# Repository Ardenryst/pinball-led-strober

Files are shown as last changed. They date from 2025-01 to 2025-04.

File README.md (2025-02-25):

# Project description

This is a simple platform to add mods with light effects to an existing pinball machine.
The board connected to an existing lamp and once this lights up, the boards triggers its own animation. Simple as that.

Find details about hardware and firmware in their respective folders.

This project is free hardware/software, use it for your own projects if your like and let me know when you made something great!

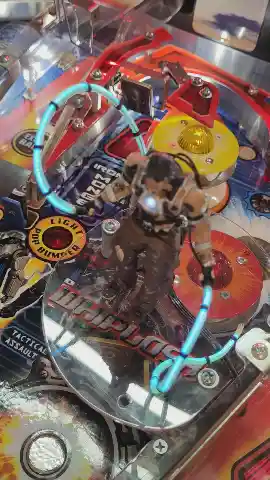
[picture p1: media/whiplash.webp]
Whiplash


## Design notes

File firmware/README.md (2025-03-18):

# Firmware

Firmware is written in C and has no external dependencies.

**Info** This software is very minimal and likely to change in the future.

## Building

While this is NOT an Arduino project, the easiest way to get all the necessary development tools is in fact to use what comes bundled with Arduino. If you already have Arduino installed, follow these steps, otherwise I'd recommend using `arduino-cli` instead.

### Setup using Arduino

So you're already using Arduino? Then you can use that. But first you may have to install the package `ATTinyCore` via the board manager. This may require to add the line `http://drazzy.com/package_drazzy.com_index.json` to "Additional Boards Manager URLs". **Nope, not needed!**

### Setup using arduino-cli

 > **This is nonsense! Headers and advdude config is part of arduino distribution already! But I think this still need to be installed as cli comes without any cores, correct?**

This option saves a lot of the bloat that comes with a standard Arduino installation.

1. Check the documentation for the preferred way to install `arduino-cli` on your platform. Then enter the terminal.

2. Install core: `arduino-cli core install arduino:avr`

3. `arduino-cli config dump` to check the directories you have to look for the toolchain to complete the next step. These are located under `directories>data`.

### Configure build system

The firmware is build via `make`. This tool is pre-installed under many systems, for Windows the easiest way would be to use `WSL`.

To tell it where your compiler and other tools are, an `Makefile.in` file is required. You can use copy the existing `Makefile.in.template` and adjust it to your needs. There is example configurations for both Mac and Linux included. Find the base path in the output from the previous step.

Make sure to correctly set the paths that point to the tool binaries, depending on your specific machine setup and program versions these may vary.

### Compile

Run `make` from the firmware root directory to build the software.

### Set fuses

To prime chip the fuse bits have to be flashed first. This configures hardware functions like clock speed etc. of the MCU. Use `make burn_fuses` for this. This has only to be done once since uploading firmware file does not touch the fuse settings.

### Upload firmware

Run `make program` to flash the firmware. This will upload the build to the target. The execution should start immediately once upload is completed.

`make && make program` will rebuild the project and, if successful, then upload it. This is convenient during development.

## Changing animation

There is no way to configure anything at this point, you'll have to hack away at the code. This should be easy enough for everyone who is familiar with C to some degree, since the code is really not that complex.

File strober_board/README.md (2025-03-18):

# Hardware description

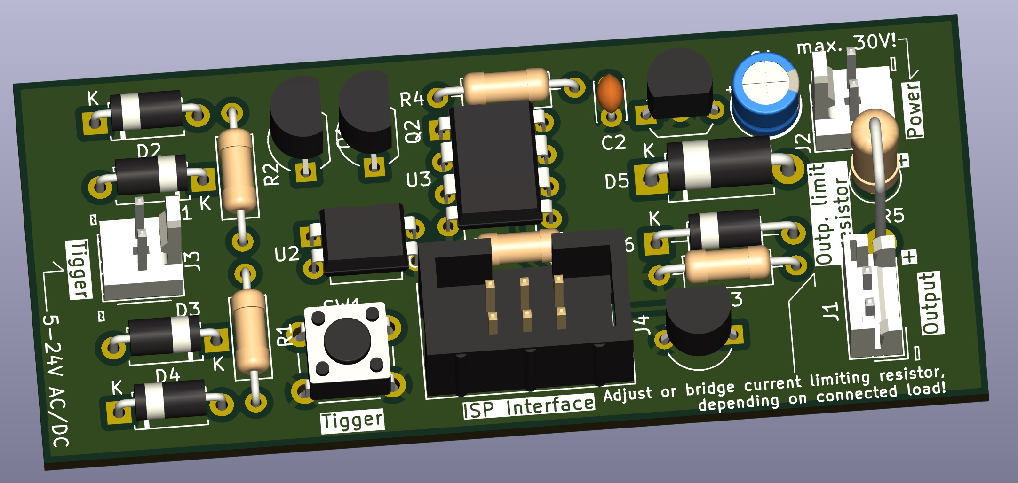
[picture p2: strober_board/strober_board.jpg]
Title


The hardware is build around the `Attiny85` microcontroller (MCU), a cheap yet capable chip. To program the firmware onto the controller, an ISP (in-system programmer) is needed. You can also use something like an Arduino with the correct sketch loaded onto it.

The electronics need an external supply of 8-30V DC, reverse polarity protected local regulation is on board. The animation is triggered by an external current, the board is intended to be connected to an existing lamp and triggers as soon as this turns on. The trigger input can accept a wide voltage range of 5 to at least 24V, with no concern to polarity. For testing there is also a trigger button on the board itself that simulates an external event. Trigger input is galvanically isolated from rest of curcuit via an opto-coupler, to avoid issues with matrix switching or split power rails.

The output is connected to the board supply voltage through a current limiting resistor (R5), that has to be selected for the connected load or bridged with a jumper, if not needed. The MCU controls the output with a 12bit PWM signal, thus allowing 4096 levels of brightness with smooth fading. Output is protected against back EMF from inductive loads (e.g. EL-Wire power supply) and can supply up to 500mA of continious current.

The PCB design can either be send to a manufacturer (use the includes `Gerber-files`) or build on a commonly availible 10x23 hole proto board. Both options share the same physical board size of 30x70mm. Take a look into the interactive bill of materials `bom-folder` for what parts need to be sourced - it also greatly helps in assembly!

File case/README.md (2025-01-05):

# Part description

This is a simple casing, that can be used to mount the board under the playfield using 2-4 #8 wood screws, as they are commonly found in virtually every pinball machine ever produced.
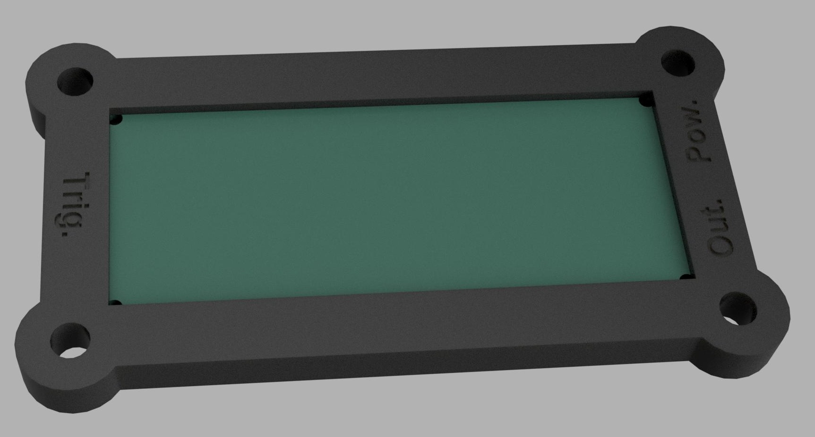
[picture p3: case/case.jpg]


The case consist of two pieces and can be created without any special settings or support structures on practically any 3D printer.

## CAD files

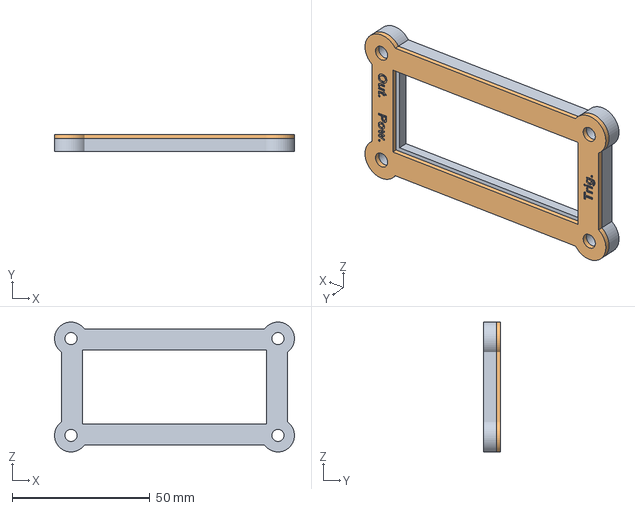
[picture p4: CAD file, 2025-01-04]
case/case.3mf
87.2 x 6.10 x 47.2 mm

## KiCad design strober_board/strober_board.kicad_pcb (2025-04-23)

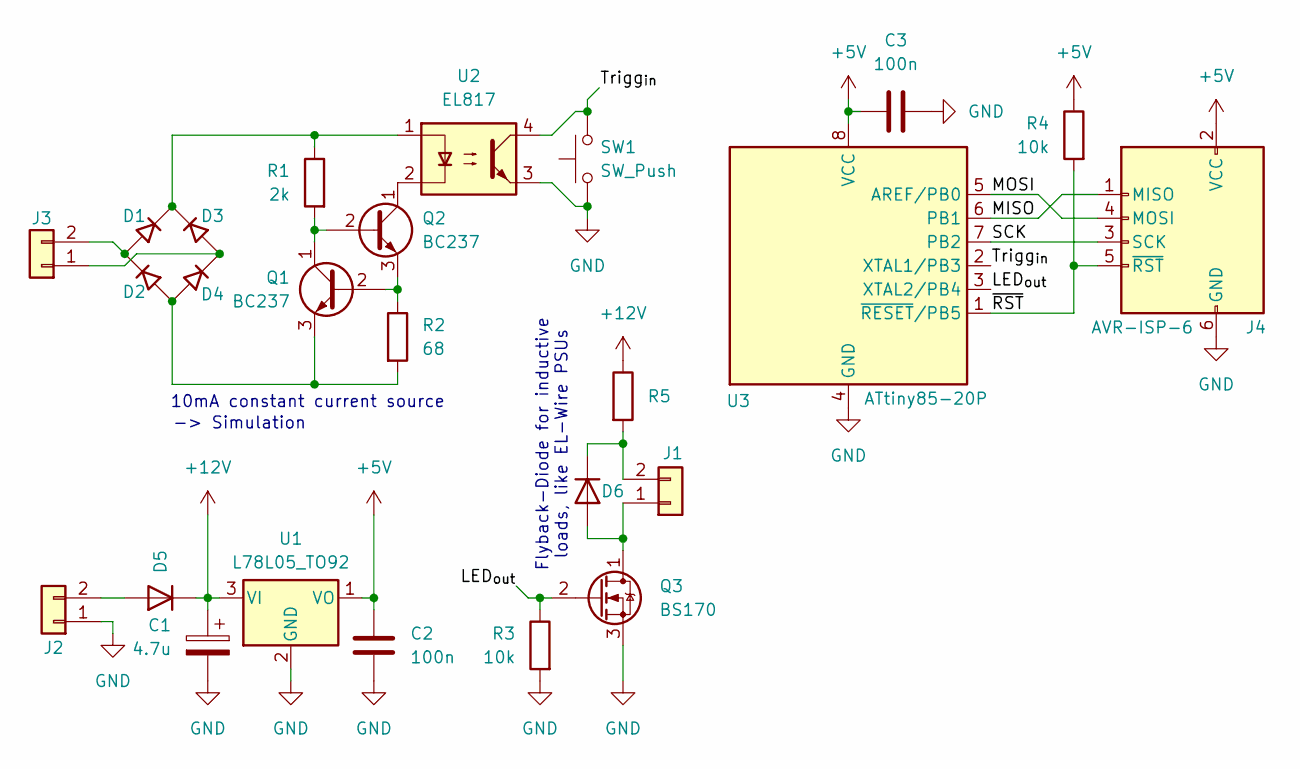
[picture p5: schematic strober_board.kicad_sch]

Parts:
C1: 4.7u; CP_Radial_D5.0mm_P2.50mm
C2: 100n; C_Disc_D3.0mm_W2.0mm_P2.50mm
C3: 100n; R_Axial_DIN0207_L6.3mm_D2.5mm_P10.16mm_Horizontal
D1, D2, D3, D4: D_45deg; D_A-405_P7.62mm_Horizontal
D5: D; D_DO-15_P10.16mm_Horizontal
D6: D; D_A-405_P10.16mm_Horizontal
J1: Conn_01x02; JST_EH_B2B-EH-A_1x02_P2.50mm_Vertical
J2, J3: Conn_01x02; Molex_KK-254_AE-6410-02A_1x02_P2.54mm_Vertical
J4: AVR-ISP-6; IDC-Header_2x03_P2.54mm_Vertical
Q1, Q2: BC237; TO-92_Inline_Wide
Q3: BS170; TO-92_Inline_Wide
R1: 2k; R_Axial_DIN0207_L6.3mm_D2.5mm_P10.16mm_Horizontal
R2: 68; R_Axial_DIN0207_L6.3mm_D2.5mm_P10.16mm_Horizontal
R3, R4: 10k; R_Axial_DIN0207_L6.3mm_D2.5mm_P10.16mm_Horizontal
R5: R_Axial_DIN0411_L9.9mm_D3.6mm_P5.08mm_Vertical
SW1: SW_Push; SW_PUSH_6mm
U1: L78L05_TO92; TO-92_Inline_Wide
U2: EL817; DIP-4_W7.62mm
U3: ATtiny85-20P; DIP-8_W7.62mm

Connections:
+5V: C2.2, C3.1, J4.2 (VCC), R4.1, U1.1 (VO), U3.8 (VCC)
+12V: C1.1, D5.1 (K), R5.1, U1.3 (VI)
/LED_{out}: Q3.2 (G), R3.1, U3.3 (XTAL2/PB4)
/MISO: J4.1 (MISO), U3.6 (PB1)
/MOSI: J4.4 (MOSI), U3.5 (AREF/PB0)
/SCK: J4.3 (SCK), U3.7 (PB2)
/Trigg_{in}: SW1.2, U2.4, U3.2 (XTAL1/PB3)
/~RST: J4.5 (~RST), R4.2, U3.1 (~RESET/PB5)
GND: C1.2, C2.1, C3.2, J2.1, J4.6 (GND), Q3.3 (S), R3.2, SW1.1, U1.2 (GND), U2.3, U3.4 (GND)
unnamed: D1.2 (A), D2.1 (K), J3.2
unnamed: D1.1 (K), D3.1 (K), R1.1, U2.1
unnamed: D2.2 (A), D4.2 (A), Q1.3 (E), R2.2
unnamed: D3.2 (A), D4.1 (K), J3.1
unnamed: D5.2 (A), J2.2
unnamed: D6.2 (A), J1.1, Q3.1 (D)
unnamed: D6.1 (K), J1.2, R5.2
unnamed: Q1.2 (B), Q2.3 (E), R2.1
unnamed: Q1.1 (C), Q2.2 (B), R1.2
unnamed: Q2.1 (C), U2.2

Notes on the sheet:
Flyback-Diode for inductive loads, like EL-Wire PSUs
-> Simulation
10mA constant current source

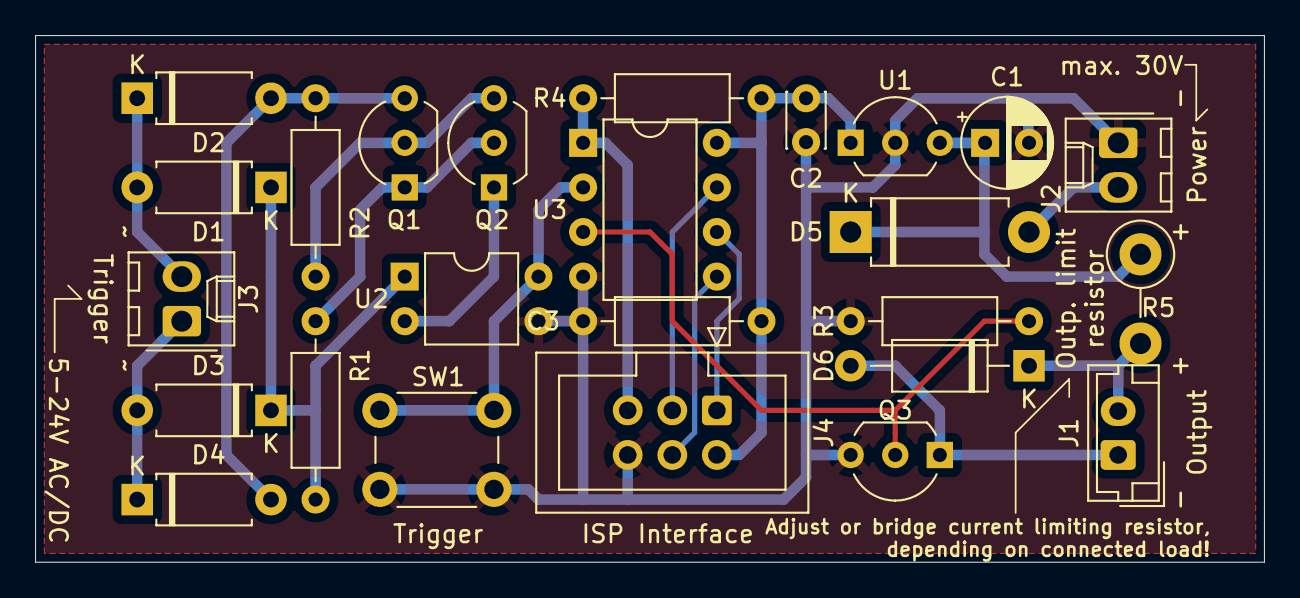
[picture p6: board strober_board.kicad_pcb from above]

Board: 2 copper layers, 70.0 x 30.0 mm, 25 parts (0 on the bottom side), 19 nets.

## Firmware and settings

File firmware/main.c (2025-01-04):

#include <stdlib.h>
#include <stdio.h>
#include <stdbool.h>
#include <stdint.h>
#include <string.h>

#include <util/delay.h>
#include <avr/io.h>
#include <avr/eeprom.h>
#include <avr/interrupt.h>
#include <util/atomic.h>
#include <avr/pgmspace.h>

#include <util.h>

#define LED   B, 4
#define TX    B, 2
#define BTN   B, 3
static volatile uint8_t* pwm_channels[] = { &OCR1B, /*&OCR1A */};

// Source: https://www.mikrocontroller.net/topic/311610#3362049
int uart_putchar(char c, FILE *stream) {
  #define DEBUG_PIN B, 2

  #define DEBUG_HIGH  PORT(DEBUG_PIN) = 1
  #define DEBUG_LOW  PORT(DEBUG_PIN) = 0

  //Wartezeit in us 
  #define MINDELAY    104     // fuer 9600 bps
  // #define MINDELAY    26     // fuer 38400 bps
  // #define MINDELAY   417    // fuer 2400 bps ACHTUNG nicht mit _delay_us machtbar!!
                // zumindest nicht als einzelner aufruf!
  OUTPUT(DEBUG_PIN);
  PORT(DEBUG_PIN) = 1;

  PORT(DEBUG_PIN) = 0;
  _delay_us(MINDELAY);               // Start Bit

  for(uint8_t i=0; i<8; i++) {
    if(c & (0x01<<i)) {
      PORT(DEBUG_PIN) = 1;
    } else {
      PORT(DEBUG_PIN) = 0;
    }
    _delay_us(MINDELAY);
  }
  PORT(DEBUG_PIN) = 1;        // Stop Bit
  _delay_us(MINDELAY);

  return 0;
}

// Higher bit PWM sources:
//  - https://www.arduinoslovakia.eu/blog/2017/12/10-bitove-pwm-na-attiny85?lang=en
//  - http://www.technoblogy.com/show?1NGL

volatile int dac[SIZE(pwm_channels)];

void initPWM() {
 OCR1C = 255;
  // Timer/Counter1 doing PWM on OC1A (PB1)
  TCCR1 = 1 << PWM1A    // Pulse Width Modulator A Enable
          | 1 << COM1A0 // OC1x cleared on compare match. Set when TCNT1 = $00
          | 0 << CS10 | 0 << CS11 | 1 << CS12;  // TODO prüfen, ob man das so macht. Durch rumprobieren bei 250Hz PWM-Frew gelandet.
  TIMSK |= 1 << TOIE1; // Timer/Counter1 Overflow Interrupt Enable
  
  GTCCR = 1<<PWM1B | 1<<COM1B1; // What kind of shitty register naming is that?!
}

// 12bit DAC
// Overflow interrupt
ISR(TIMER1_OVF_vect) {
  static volatile int cycle = 0;
  static int rem[SIZE(pwm_channels)];
  for(int chan=0; chan<SIZE(pwm_channels); chan++) {
    int remain;
    if(cycle==0) {
      remain = dac[chan];
    } else {
      remain = rem[chan];
    }
    if(remain>=256) {
      *pwm_channels[chan] = 255; remain = remain - 256;
    } else {
      *pwm_channels[chan] = remain; remain = 0;
    }
    rem[chan] = remain;
  }
  cycle = (cycle+1) & 0x0F;
}

const uint16_t PROGMEM gamma_8b[] = {
  0,    0,    0,    0,    1,    1,    2,    3,    4,    6,    8,   10,   13,   16,   19,   24,
  28,   33,   39,   46,   53,   60,   69,   78,   88,   98,  110,  122,  135,  149,  164,  179,
  196,  214,  232,  252,  273,  295,  317,  341,  366,  393,  420,  449,  478,  510,  542,  575,
  610,  647,  684,  723,  764,  806,  849,  894,  940,  988, 1037, 1088, 1140, 1194, 1250, 1307,
  1366, 1427, 1489, 1553, 1619, 1686, 1756, 1827, 1900, 1975, 2051, 2130, 2210, 2293, 2377, 2463,
  2552, 2642, 2734, 2829, 2925, 3024, 3124, 3227, 3332, 3439, 3548, 3660, 3774, 3890, 4008, 4128,
  4251, 4376, 4504, 4634, 4766, 4901, 5038, 5177, 5319, 5464, 5611, 5760, 5912, 6067, 6224, 6384,
  6546, 6711, 6879, 7049, 7222, 7397, 7576, 7757, 7941, 8128, 8317, 8509, 8704, 8902, 9103, 9307,
  9514, 9723, 9936, 10151, 10370, 10591, 10816, 11043, 11274, 11507, 11744, 11984, 12227, 12473, 12722, 12975,
  13230, 13489, 13751, 14017, 14285, 14557, 14833, 15111, 15393, 15678, 15967, 16259, 16554, 16853, 17155, 17461,
  17770, 18083, 18399, 18719, 19042, 19369, 19700, 20034, 20372, 20713, 21058, 21407, 21759, 22115, 22475, 22838,
  23206, 23577, 23952, 24330, 24713, 25099, 25489, 25884, 26282, 26683, 27089, 27499, 27913, 28330, 28752, 29178,
  29608, 30041, 30479, 30921, 31367, 31818, 32272, 32730, 33193, 33660, 34131, 34606, 35085, 35569, 36057, 36549,
  37046, 37547, 38052, 38561, 39075, 39593, 40116, 40643, 41175, 41711, 42251, 42796, 43346, 43899, 44458, 45021,
  45588, 46161, 46737, 47319, 47905, 48495, 49091, 49691, 50295, 50905, 51519, 52138, 52761, 53390, 54023, 54661,
  55303, 55951, 56604, 57261, 57923, 58590, 59262, 59939, 60621, 61308, 62000, 62697, 63399, 64106, 64818, 65535
};

// more or less copy pasted and updated, with no real idea what I was doing. Seems to work OK though...
uint16_t correctGamma12(uint16_t value) {
  uint16_t y = pgm_read_word(&gamma_8b[value / 16]);
  uint16_t z1 = (value / 16 == 0) ? 0 : pgm_read_word(&gamma_8b[value / 16 - 1]);
  uint16_t z = (y - z1) / 16 * (value % 16 + 1) + z1;

  return z >> 6;
}

const uint8_t exptable5[32] PROGMEM =
  {130, 133, 136, 139, 142, 145, 148, 151, 155, 158, 161, 165, 169, 172, 176, 180,
  184, 188, 192, 196, 201, 205, 210, 214, 219, 224, 229, 234, 239, 244, 249, 255};

/*inline*/ uint16_t expvalue9(const uint16_t linear)
{/* Returns the exponential value (approx. 1.0219^x).                          *
  * argument: 9 bit unsigned (0..511)  return: 16 bit unsigned (1..65280)    */
  // look up exponential
  uint16_t exp = pgm_read_byte(&exptable5[ linear % 32 ]) << 8;
  // scale magnitude
  return exp >> (15 - linear / 32);
}

// #define BASE_BRIGHTNESS 20
// // #define MAX_BRIGHTNESS 100
// #define BRIGHTNESS_VARIANCE (100-BASE_BRIGHTNESS)

// Basishelligkeit, bezogen auf max. Umgebungshelligkeit
#define BASE_BRIGHTNESS 3000
// +/- var/2 auf Basishelligkeit
#define BRIGHTNESS_VARIANCE 2200
// Faktor für Überhöhung der Bezugshelligkeit aus der Umgebung
#define ELEVATION 1.3

#define MIN_FADE_TIME 50
#define FADE_TIME_VARIANCE 100

#define MIN_HOLD_TIME 100
#define HOLD_TIME_VARIANCE 200

struct Led {
  volatile int *dac;
//   const uint16_t MIN_BRIGHTNESS;
  // const uint16_t MAX_BRIGHTNESS;
  struct Timer fade_timer;
  uint16_t start;
  uint16_t goal;
} leds[] = {
  {.dac = &dac[0]},
};
inline void fade(struct Led *led, uint16_t from, uint16_t to, uint16_t duration) {
  resetTimer(&led->fade_timer);
  led->fade_timer.cycle = duration;
  led->start = from;
  led->goal = to;
}

// struct {
//   bool is_pushed;
//   //uint8_t samples;
//   struct Timer sample_timer;
// } button = {false, 0, {1}};

int main() {
  initMillis();
  initPWM();
  
  FILE soft_uart = FDEV_SETUP_STREAM(uart_putchar, NULL, _FDEV_SETUP_WRITE);
  stdout = &soft_uart;
  
  OUTPUT(LED);
  OUTPUT(TX);
  INPUT_PULLUP(BTN);
  
  enum States {INIT, STANDBY, FLASH};
  struct StateMachine fsm;
  initFSM(&fsm, INIT);
  
  // #define MAX_BRIGHTNESS 4096
  // #define MIN_BRIGHTNESS 0
  // #define DURATION 10000
  
  // struct Timer timer = {.cycle=DURATION};
  // bool dir = true;
  while(true) {
    // if(checkAndResetTimer(&timer)) {
    //   dir = !dir;
    //   fade(&leds[0], dir ? MAX_BRIGHTNESS : MIN_BRIGHTNESS, dir ? MIN_BRIGHTNESS: MAX_BRIGHTNESS, DURATION);
    // }
    
//     if(checkAndResetTimer(&button.sample_timer)) {
//       if(PIN(BTN)==0) {
//         if(button.samples < 10) {
//           button.samples++;
//         } else {
//           if(!button.is_pushed) {
//             transit(&fsm, fsm.current_state == ON ? OFF : ON);
//             button.is_pushed = true;
//           }
//         }
//       } else {
//         button.samples = 0;
//         button.is_pushed = false;
//       }
//     }
//    

    struct Led *led = &leds[0];
    
    switch(updateFSM(&fsm)) {
      case INIT:
        // fade(led, 0, 0, 1000);
        transit(&fsm, STANDBY);
        break;
      case STANDBY:
        if(onEnter(&fsm)) {
          fade(led, led->goal, 0, 1000);
        }
        if(PIN(BTN)==0) {
          transit(&fsm, FLASH);
        }
        break;
      case FLASH: {
        static bool cooldown;
        static struct Timer timer = {.cycle=3000};
        if(onEnter(&fsm)) {
          fade(led, 0, BASE_BRIGHTNESS+BRIGHTNESS_VARIANCE/2, 10);
          cooldown = false;
          resetTimer(&timer);
        }
        if(checkTimer(&timer)) {
          transit(&fsm, STANDBY);
        }
        if(checkAndResetTimer(&led->fade_timer)) {
          if(cooldown) { // Helligkeit eine Weile beibehalten
            cooldown = false;
            uint16_t duration = MIN_HOLD_TIME+(rand() / (RAND_MAX / HOLD_TIME_VARIANCE + 1));
            fade(led, led->goal, led->goal, duration);
          } else {              // Neue Helligkeit setzen
            cooldown = true;
            // Halbe Helligkeit + Zufallswert mit +- Varianz/2
            int16_t to = BASE_BRIGHTNESS+(-BRIGHTNESS_VARIANCE/2 + (rand() / (RAND_MAX / BRIGHTNESS_VARIANCE + 1)));
            uint16_t duration = MIN_FADE_TIME+(rand() / (RAND_MAX / FADE_TIME_VARIANCE + 1));
//             to = 512;
//             duration = 500;
            fade(led, led->goal, to, duration);
          }
        }
        break;
      }
    }
    
    // update PWM channels
    for(unsigned int index=0; index<SIZE(leds); index++) {
      struct Led *led = &leds[index];
      
      uint16_t brightness = ((int16_t)0)+linearInterpolate(led->start, led->goal, &led->fade_timer);
      brightness = correctGamma12(brightness);
      
      ATOMIC_BLOCK(ATOMIC_FORCEON) {
        *led->dac = brightness;
      }
    }
    
//     FOR_ALL_CHANNELS {
//       #define scale(val, fac) (((uint32_t)val)*fac*4096)/4096;
//       uint16_t environ = scale(ldr_adc, ELEVATION);
//       // Mindesthelligkeit begrenzen
//       environ = min(max(environ, 500), 4096);
// //       environ = 4096;
//       
//       uint16_t brightness = ((int16_t)0)+linearInterpolate(led->start, led->goal, &led->fade_timer);
//       uint16_t led_max = (((uint32_t)environ)*(led->MAX_BRIGHTNESS))/4096;
//       uint16_t led_min = 0; //fsm.last_state == OFF ? 0 : (((uint32_t)ldr_adc)*(led->MIN_BRIGHTNESS))/1023;
//       brightness = (((uint32_t)brightness)*(led_max-led_min))/4096+led_min;
// //       if(index==0) printf("Brightness: %d\n", environ);
//       
//       ATOMIC_BLOCK(ATOMIC_FORCEON) {
//         *led->dac = brightness; //correctGamma(brightness); ldr_adc; //
//       }
//     }
  }
}

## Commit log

2025-01-04 added hardware files
    [strober_board.kicad_pcb, strober_board.kicad_sch]
2025-01-04 Production files and HW Readme
    [strober_board-B_Cu.gbr, strober_board-B_Mask.gbr, strober_board-B_Paste.gbr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]
2025-01-04 3D printed case
    [case.3mf]
2025-01-04 changed connectors
    [strober_board.kicad_pcb, strober_board.kicad_sch]
2025-01-04 compacted layout
    [strober_board.kicad_pcb]
2025-01-05 firmware readme
    [strober_board.kicad_pcb, strober_board.kicad_sch]
2025-03-11 Fixed reverse polarity protection
    [strober_board.kicad_pcb, strober_board.kicad_sch]
2025-03-11 minor board update
    [strober_board.kicad_sch]
2025-03-11 burn fuses
2025-03-11 Chapter fuse in readme
2025-04-23 fix silkscreen typo
    [strober_board-B_Cu.gbr, strober_board-B_Mask.gbr, strober_board-B_Paste.gbr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]
